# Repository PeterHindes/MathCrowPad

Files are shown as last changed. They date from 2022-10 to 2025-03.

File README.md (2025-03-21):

# MathCrowPad

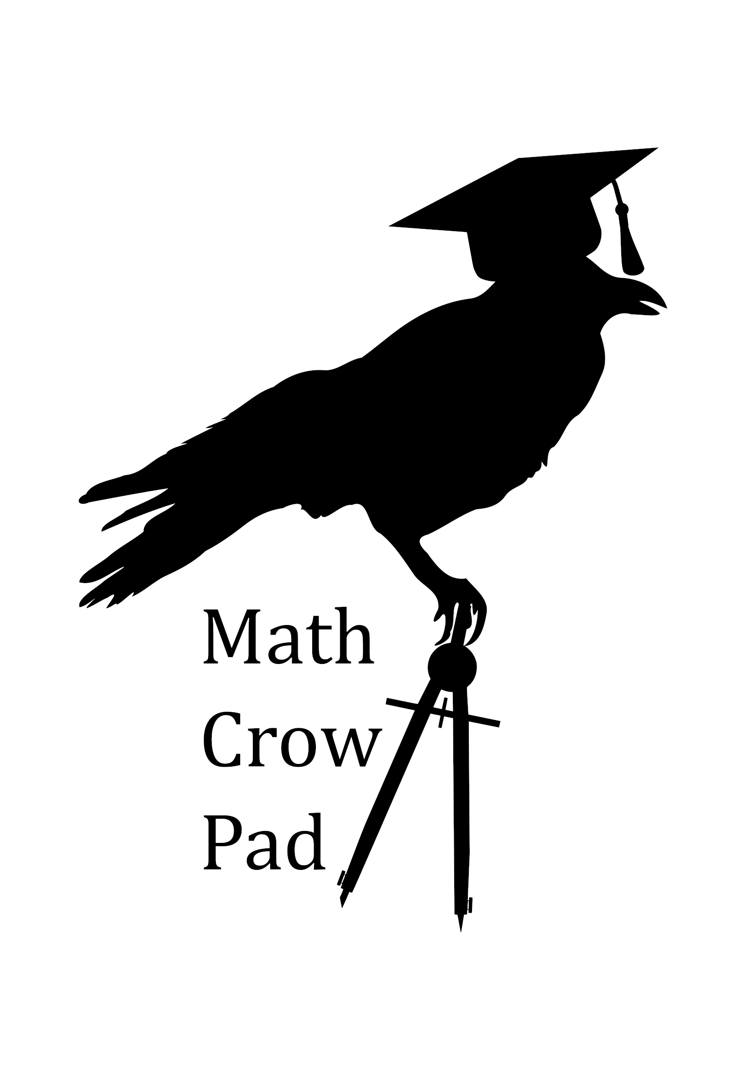
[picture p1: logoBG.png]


## The MathCrowPad is a numberpad for chemistry, math, and spreadsheets.

Its main three features are:
 * Two knobs to scroll through spreadsheets
 * An oled screen to show guides for the knobs
 * An extra row for parenthisis(), exponent^, factorial!, latex syntax$$ etc.

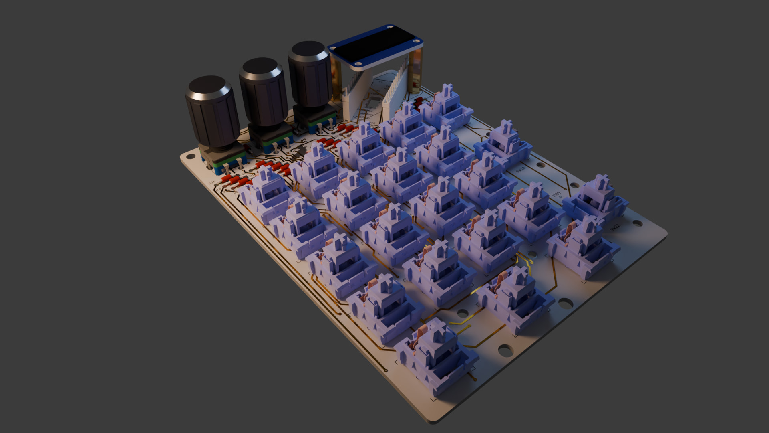
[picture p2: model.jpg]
model


Feel free to make up to 10 for personal use.

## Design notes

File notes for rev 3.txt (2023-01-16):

north facing leds are better for backlight shinethroughs
encoders with a single pad works gread

might need a diffrent footprint for bluetooth controllers
https://www.adafruit.com/product/5426

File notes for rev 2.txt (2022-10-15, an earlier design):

Issues with rev1:
X-The led library I made has the wrong pins -- Fixed rev2
X-The two top rotary encoders are not electricaly connected to ground, the ground plane is dissconnected -- removed ground plane, used new router, fixed
The rotary encoder non electrical holes are not plated for soldering -- fixed
Probably want to use a plate mount for v2 -- Holes added, check cad before order
screw hole on the bottom right, the screw head causes friction with the stabilizer bar -- fixed
stabilizer stickers cover the vanity logos -- logos removed
The miso pin may be a better driver for the rgb backlight look into qmk drivers -- used, testing needed when sample recived

Other Notes:
reset button on the kb2040 is hard to press when bottom mounted, top mount is possible with rev1 but not tested -- top mounted design complete
possibly add side mounted reset button to board like levinson -- not needed see above
unfixable without plate, switches lift up from unsoldered side
Matrix is not aligned with the key positions in the keymap. Perhaps the enter key should be moved up in th ematrix and the add key
The South paw logo is too small
Logos on back will be covered -- removed

Hardware Parts Selection:
The rotary encoders appear to trigger a rotation when they are clicked -- This may be a design error, investigating
Will need to order more kb2040s -- done

Current Design Notes TODO
X-no clearance for stema connector on top mounted design, route cable between keys with underside cutout -- replaced with rotated mount design
X-Consider pin socketed mounting -- done
X-consider hot swap keys -- incorporated in design
design needs to use switch plate which will require diffrent stabilizers -- ordered, check plate pattern fits in progress
Use jumpers to choose fast led or nkr for encoders

The CAD model for the oled does not line up with the screw holes

consider product name "Math Crow Pad" logo of a crow with a graduation cap

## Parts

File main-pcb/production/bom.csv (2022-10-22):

Designator | Footprint | Quantity | Value | LCSC Part #
D1, D10, D11, D12, D13, D14, D15, D16, D17, D18, D19, D2, D20, D21, D22, D23, D24, D25, D3, D4, D5, D6, D7, D8, D9 | Diode-dual | 25 | DIODE
FID1 | Fiducial_0.5mm_Mask1mm | 1 | Fiducial
JPSH1 | SolderJumper-3_P2.0mm_Open_TrianglePad1.0x1.5mm | 1 | Jumper_3_Open
JPSP2, JPSP3 | SolderJumper-2_P1.3mm_Open_TrianglePad1.0x1.5mm | 2 | Jumper_2_Open
RSW1, RSW2, RSW3 | RotaryEncoder_EC11 | 3 | RotaryEncoder_Switch
SW1, SW10, SW11, SW12, SW13, SW14, SW15, SW16, SW17, SW19, SW2, SW21, SW3, SW4, SW5, SW6, SW7, SW8, SW9 | SW_Cherry_MX_1.00u_PCB_WITH_SK6812MINI-E | 19 | SW_Push
SW18, SW20, SW22 | SW_Cherry_MX_2.00u_PCB_WITH_SK6812MINI-E | 3 | SW_Push
U1 | KB2040 through hole only (top mount with hotpins 3d model view) | 1 | KB2040

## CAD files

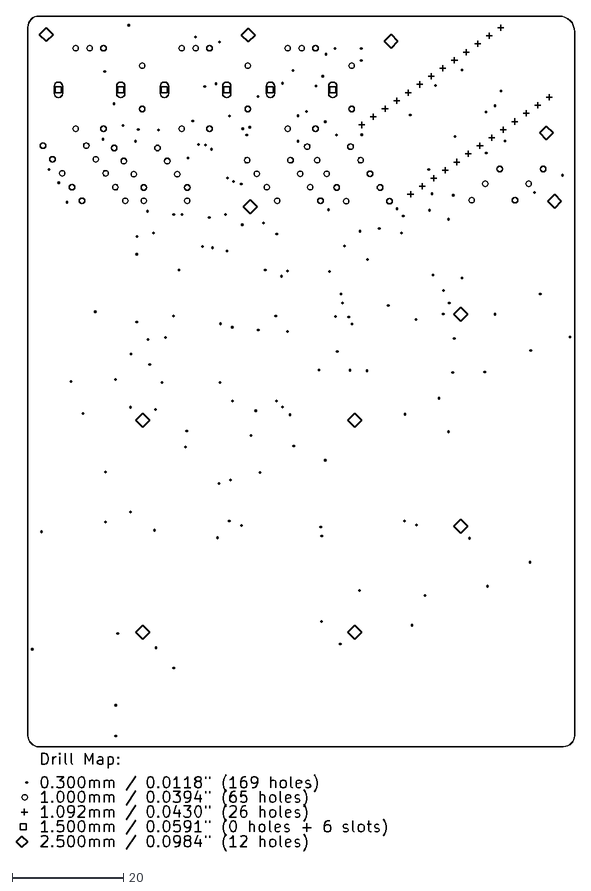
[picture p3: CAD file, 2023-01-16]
Mech Cad Files/plot/SouthPaw-PTH-drl_map.dxf
100.3 x 150.1

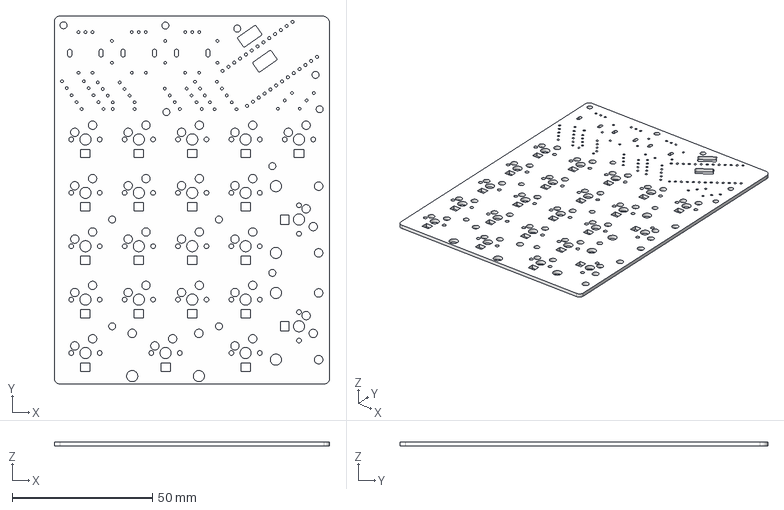
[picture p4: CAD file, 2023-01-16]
Mech Cad Files/SouthPaw PCB only.step
98.3 x 131.3 x 1.60 mm

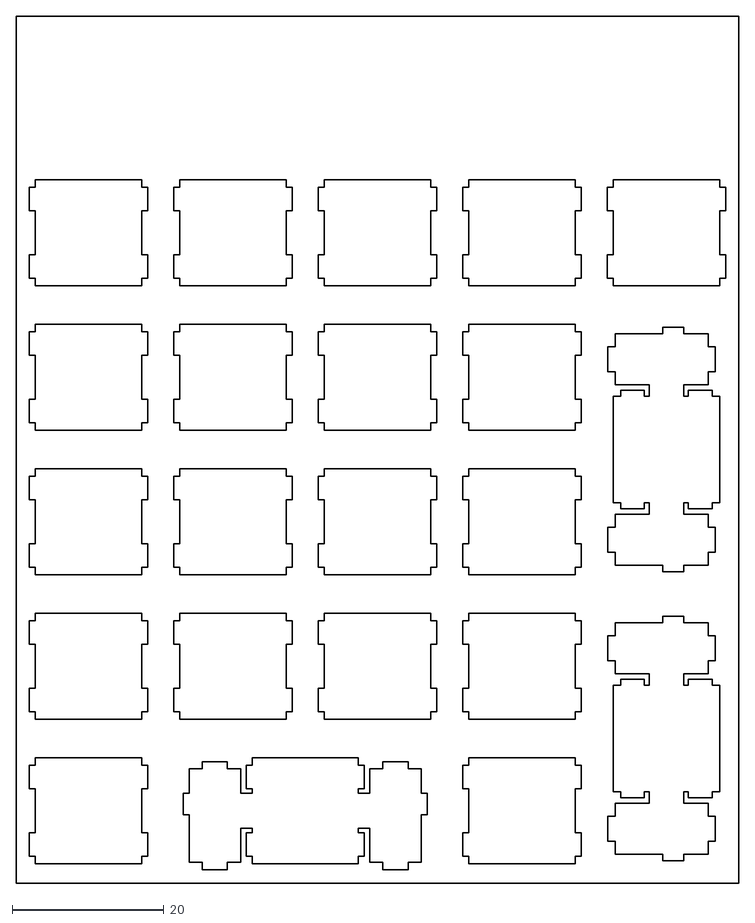
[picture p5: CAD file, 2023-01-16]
Mech Cad Files/156afa6cee5b1919b133f090e9bd5b217b3f6e2b_switch.dxf
95.3 x 114.3

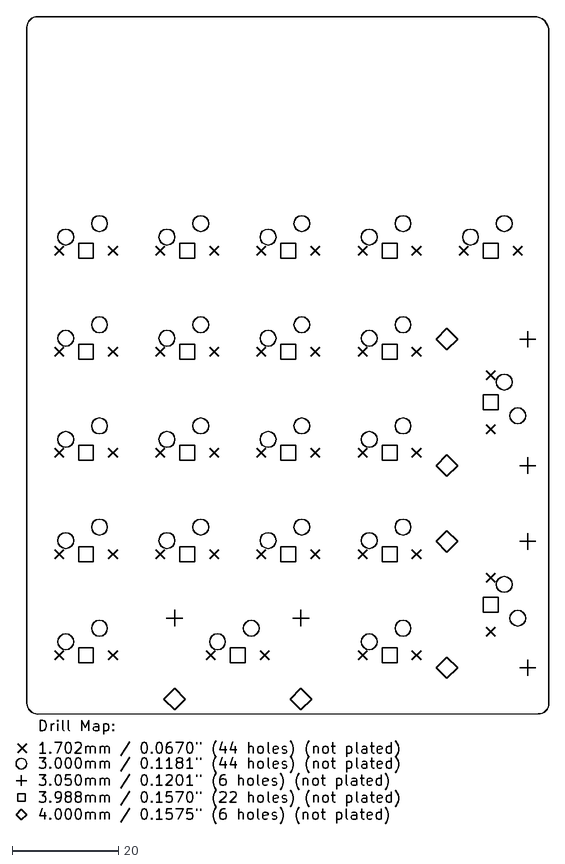
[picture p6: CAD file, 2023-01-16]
Mech Cad Files/plot/SouthPaw-NPTH-drl_map.dxf
100.3 x 152.0

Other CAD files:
Mech Cad Files/SouthPaw PCB.stl
Mech Cad Files/plot/SouthPaw-F_Mask.dxf

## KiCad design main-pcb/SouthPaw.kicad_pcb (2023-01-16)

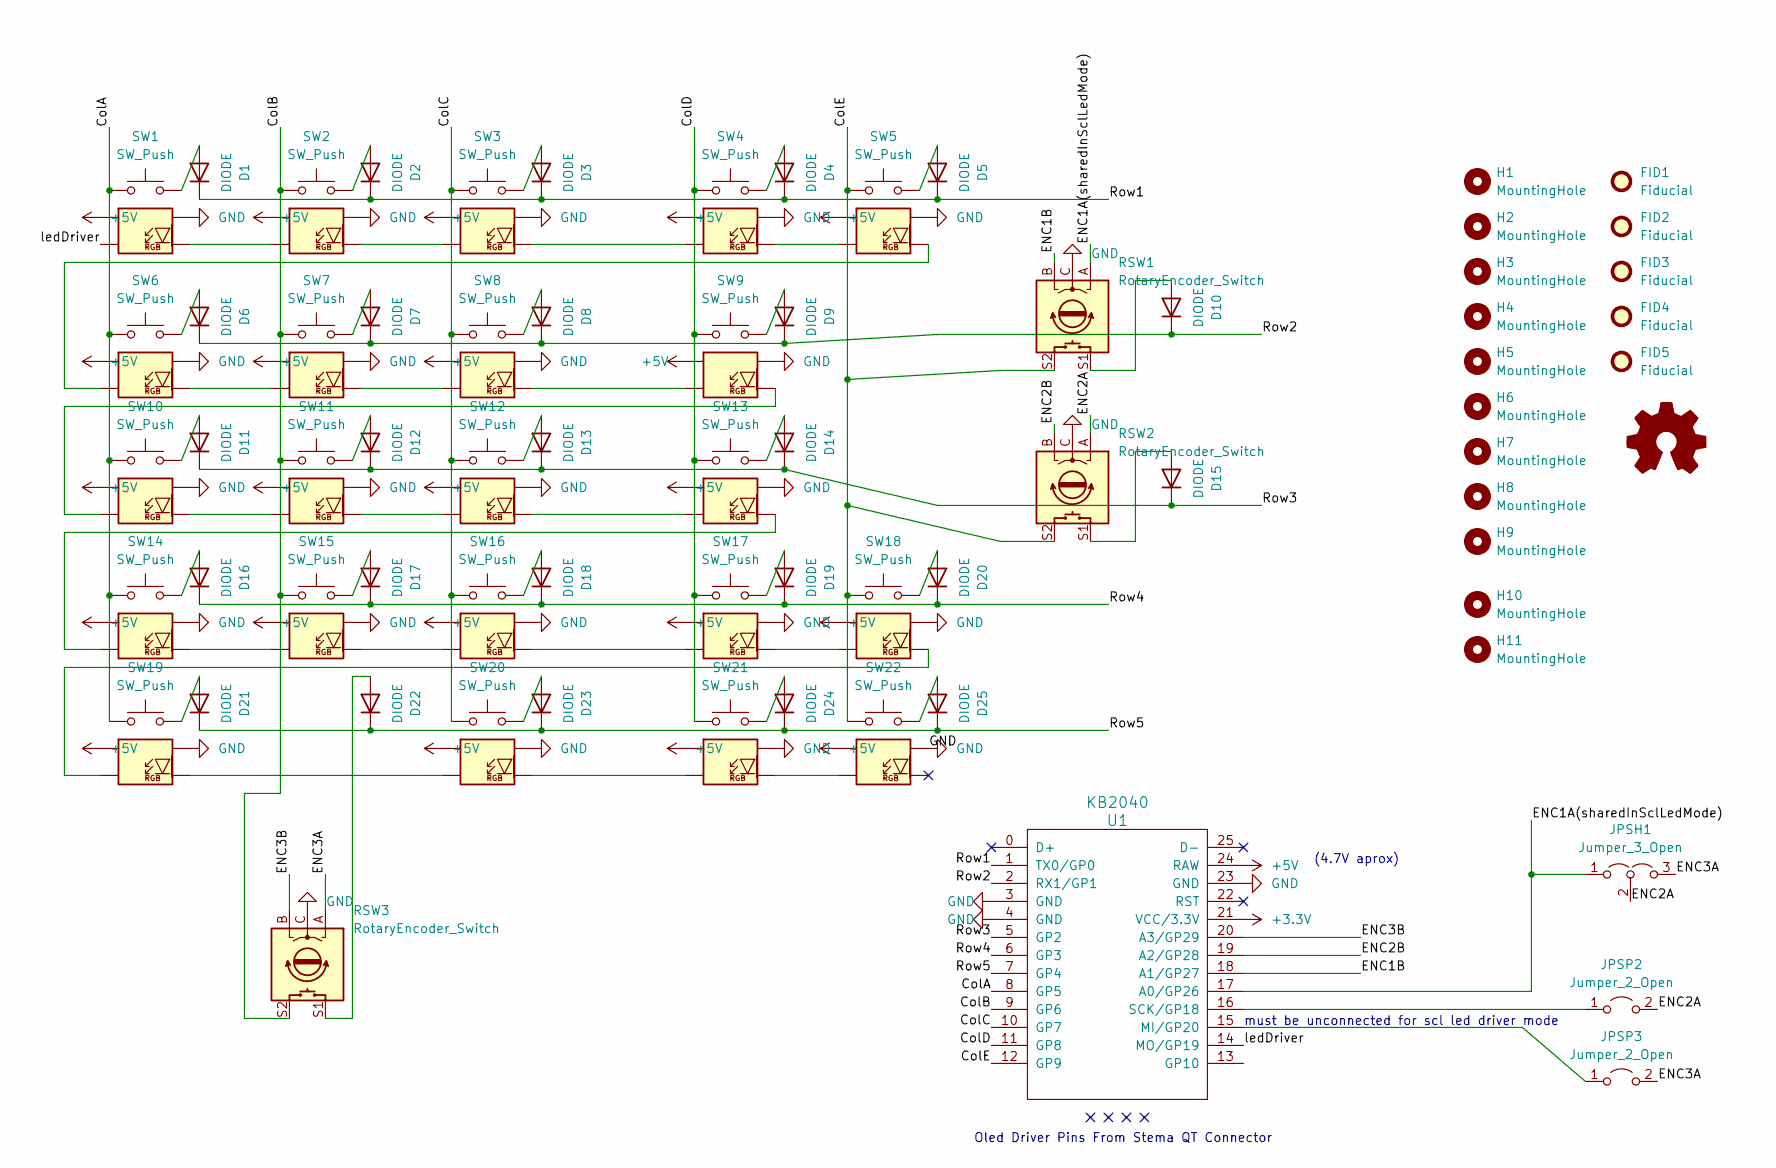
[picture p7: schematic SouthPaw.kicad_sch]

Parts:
D1, D2, D3, D4, D5, D6, D7, D8, D9, D10, D11, D12, D13, D14, D15, D16, D17, D18, D19, D20, D21, D22, D23, D24, D25: DIODE; Diode-dual
FID1, FID2, FID3, FID4, FID5: Fiducial; Fiducial_0.5mm_Mask1mm
H1: MountingHole; 0.91in 128x32 I2C STEMMA QT standoff only with cutout
H2, H3, H4, H5, H6, H7, H8, H9, H10, H11: MountingHole; m2.5 hole
JPSH1: Jumper_3_Open; SolderJumper-3_P2.0mm_Open_TrianglePad1.0x1.5mm
JPSP2, JPSP3: Jumper_2_Open; SolderJumper-2_P1.3mm_Open_TrianglePad1.0x1.5mm
RSW1, RSW2, RSW3: RotaryEncoder_Switch; RotaryEncoder_EC11
SW1, SW2, SW3, SW4, SW5, SW6, SW7, SW8, SW9, SW10, SW11, SW12, SW13, SW14, SW15, SW16, SW17, SW19, SW21: SW_Push; SW_Cherry_MX_1.00u_PCB_WITH_SK6812MINI-E
SW18, SW20, SW22: SW_Push; SW_Cherry_MX_2.00u_PCB_WITH_SK6812MINI-E
U1: KB2040; KB2040 through hole only (top mount with hotpins 3d model v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

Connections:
+3.3V: U1.21 (VCC/3.3V)
+5V: SW1.21 (ledVDD), SW2.21 (ledVDD), SW3.21 (ledVDD), SW4.21 (ledVDD), SW5.21 (ledVDD), SW6.21 (ledVDD), SW7.21 (ledVDD), SW8.21 (ledVDD), SW9.21 (ledVDD), SW10.21 (ledVDD), SW11.21 (ledVDD), SW12.21 (ledVDD), SW13.21 (ledVDD), SW14.21 (ledVDD), SW15.21 (ledVDD), SW16.21 (ledVDD), SW17.21 (ledVDD), SW18.21 (ledVDD), SW19.21 (ledVDD), SW20.21 (ledVDD), SW21.21 (ledVDD), SW22.21 (ledVDD), U1.24 (RAW)
/ColA: SW1.11 (sw1), SW6.11 (sw1), SW10.11 (sw1), SW14.11 (sw1), SW19.11 (sw1), U1.8 (GP5)
/ColB: RSW3.S2, SW2.11 (sw1), SW7.11 (sw1), SW11.11 (sw1), SW15.11 (sw1), U1.9 (GP6)
/ColC: SW3.11 (sw1), SW8.11 (sw1), SW12.11 (sw1), SW16.11 (sw1), SW20.11 (sw1), U1.10 (GP7)
/ColD: SW4.11 (sw1), SW9.11 (sw1), SW13.11 (sw1), SW17.11 (sw1), SW21.11 (sw1), U1.11 (GP8)
/ColE: RSW1.S2, RSW2.S2, SW5.11 (sw1), SW18.11 (sw1), SW22.11 (sw1), U1.12 (GP9)
/ENC1A(sharedInSclLedMode): JPSH1.1 (A), RSW1.A, U1.17 (A0/GP26)
/ENC1B: RSW1.B, U1.18 (A1/GP27)
/ENC2A: JPSH1.2 (C), JPSP2.2 (B), RSW2.A
/ENC2B: RSW2.B, U1.19 (A2/GP28)
/ENC3A: JPSH1.3 (B), JPSP3.2 (B), RSW3.A
/ENC3B: RSW3.B, U1.20 (A3/GP29)
/Row1: D1.2 (K), D2.2 (K), D3.2 (K), D4.2 (K), D5.2 (K), U1.1 (TX0/GP0)
/Row2: D6.2 (K), D7.2 (K), D8.2 (K), D9.2 (K), D10.2 (K), U1.2 (RX1/GP1)
/Row3: D11.2 (K), D12.2 (K), D13.2 (K), D14.2 (K), D15.2 (K), U1.5 (GP2)
/Row4: D16.2 (K), D17.2 (K), D18.2 (K), D19.2 (K), D20.2 (K), U1.6 (GP3)
/Row5: D21.2 (K), D22.2 (K), D23.2 (K), D24.2 (K), D25.2 (K), U1.7 (GP4)
/ledDriver: SW1.24 (ledDIN), U1.14 (MO/GP19)
GND: RSW1.C, RSW2.C, RSW3.C, SW1.23 (ledGND), SW2.23 (ledGND), SW3.23 (ledGND), SW4.23 (ledGND), SW5.23 (ledGND), SW6.23 (ledGND), SW7.23 (ledGND), SW8.23 (ledGND), SW9.23 (ledGND), SW10.23 (ledGND), SW11.23 (ledGND), SW12.23 (ledGND), SW13.23 (ledGND), SW14.23 (ledGND), SW15.23 (ledGND), SW16.23 (ledGND), SW17.23 (ledGND), SW18.23 (ledGND), SW19.23 (ledGND), SW20.23 (ledGND), SW21.23 (ledGND), SW22.23 (ledGND), U1.3 (GND), U1.4 (GND), U1.23 (GND)
unnamed: D1.1 (A), SW1.12 (sw2)
unnamed: D2.1 (A), SW2.12 (sw2)
unnamed: D3.1 (A), SW3.12 (sw2)
unnamed: D4.1 (A), SW4.12 (sw2)
unnamed: D5.1 (A), SW5.12 (sw2)
unnamed: D6.1 (A), SW6.12 (sw2)
unnamed: D7.1 (A), SW7.12 (sw2)
unnamed: D8.1 (A), SW8.12 (sw2)
unnamed: D9.1 (A), SW9.12 (sw2)
unnamed: D10.1 (A), RSW1.S1
unnamed: D11.1 (A), SW10.12 (sw2)
unnamed: D12.1 (A), SW11.12 (sw2)
unnamed: D13.1 (A), SW12.12 (sw2)
unnamed: D14.1 (A), SW13.12 (sw2)
unnamed: D15.1 (A), RSW2.S1
unnamed: D16.1 (A), SW14.12 (sw2)
unnamed: D17.1 (A), SW15.12 (sw2)
unnamed: D18.1 (A), SW16.12 (sw2)
unnamed: D19.1 (A), SW17.12 (sw2)
unnamed: D20.1 (A), SW18.12 (sw2)
unnamed: D21.1 (A), SW19.12 (sw2)
unnamed: D22.1 (A), RSW3.S1
unnamed: D23.1 (A), SW20.12 (sw2)
unnamed: D24.1 (A), SW21.12 (sw2)
unnamed: D25.1 (A), SW22.12 (sw2)
unnamed: JPSP2.1 (A), U1.16 (SCK/GP18)
unnamed: JPSP3.1 (A), U1.15 (MI/GP20)
unnamed: SW1.22 (ledDOUT), SW2.24 (ledDIN)
unnamed: SW2.22 (ledDOUT), SW3.24 (ledDIN)
unnamed: SW3.22 (ledDOUT), SW4.24 (ledDIN)
unnamed: SW4.22 (ledDOUT), SW5.24 (ledDIN)
unnamed: SW5.22 (ledDOUT), SW6.24 (ledDIN)
unnamed: SW6.22 (ledDOUT), SW7.24 (ledDIN)
unnamed: SW7.22 (ledDOUT), SW8.24 (ledDIN)
unnamed: SW8.22 (ledDOUT), SW9.24 (ledDIN)
unnamed: SW10.22 (ledDOUT), SW11.24 (ledDIN)
unnamed: SW9.22 (ledDOUT), SW10.24 (ledDIN)
unnamed: SW11.22 (ledDOUT), SW12.24 (ledDIN)
unnamed: SW12.22 (ledDOUT), SW13.24 (ledDIN)
unnamed: SW13.22 (ledDOUT), SW14.24 (ledDIN)
unnamed: SW14.22 (ledDOUT), SW15.24 (ledDIN)
unnamed: SW15.22 (ledDOUT), SW16.24 (ledDIN)
unnamed: SW16.22 (ledDOUT), SW17.24 (ledDIN)
unnamed: SW17.22 (ledDOUT), SW18.24 (ledDIN)
unnamed: SW18.22 (ledDOUT), SW19.24 (ledDIN)
unnamed: SW19.22 (ledDOUT), SW20.24 (ledDIN)
unnamed: SW20.22 (ledDOUT), SW21.24 (ledDIN)
unnamed: SW21.22 (ledDOUT), SW22.24 (ledDIN)

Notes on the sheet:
Oled Driver Pins From Stema QT Connector
must be unconnected for scl led driver mode
(4.7V aprox)

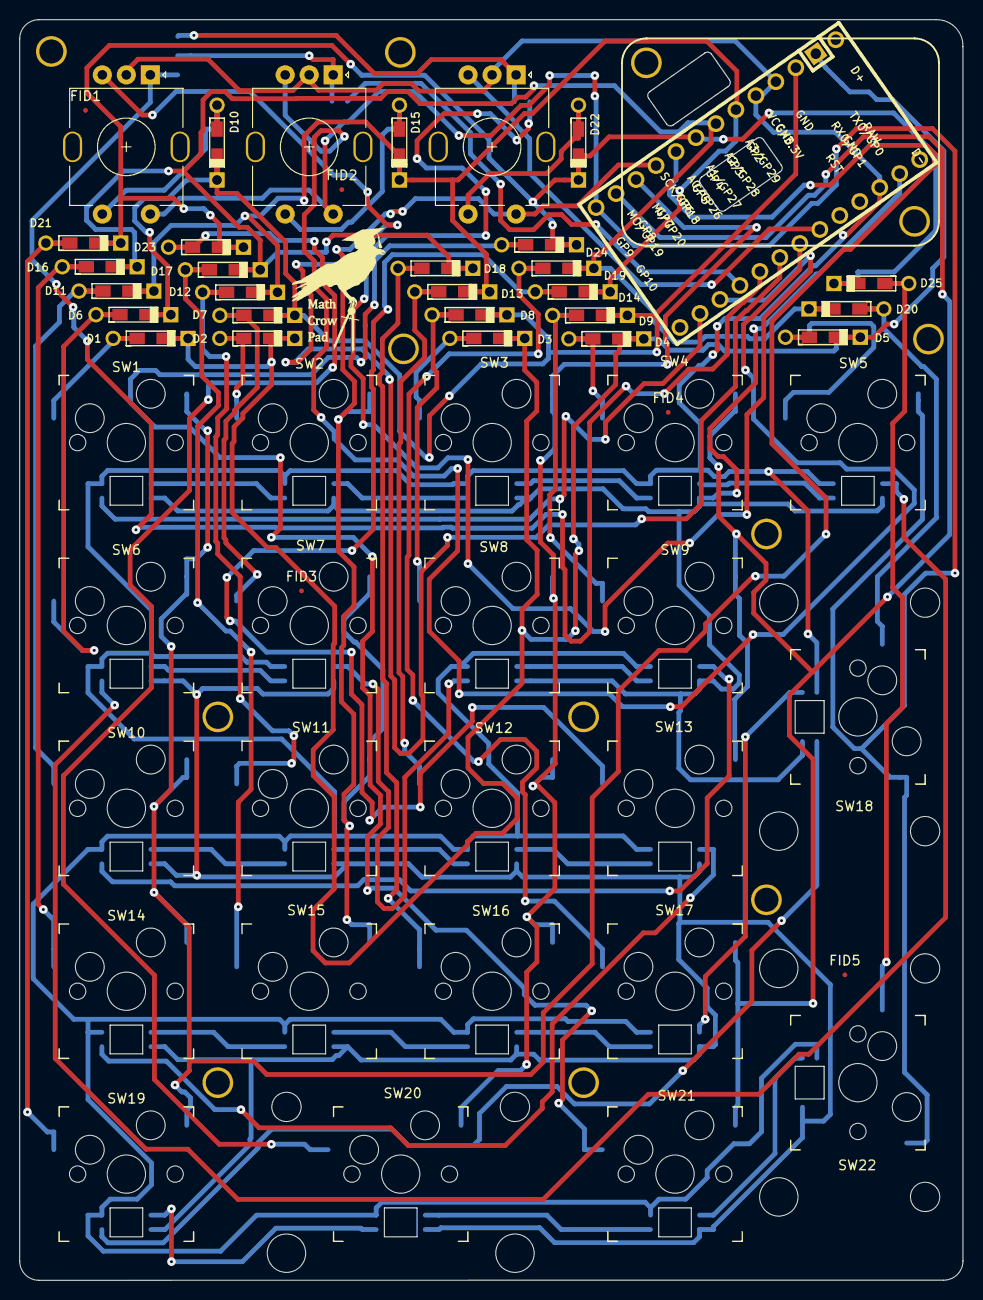
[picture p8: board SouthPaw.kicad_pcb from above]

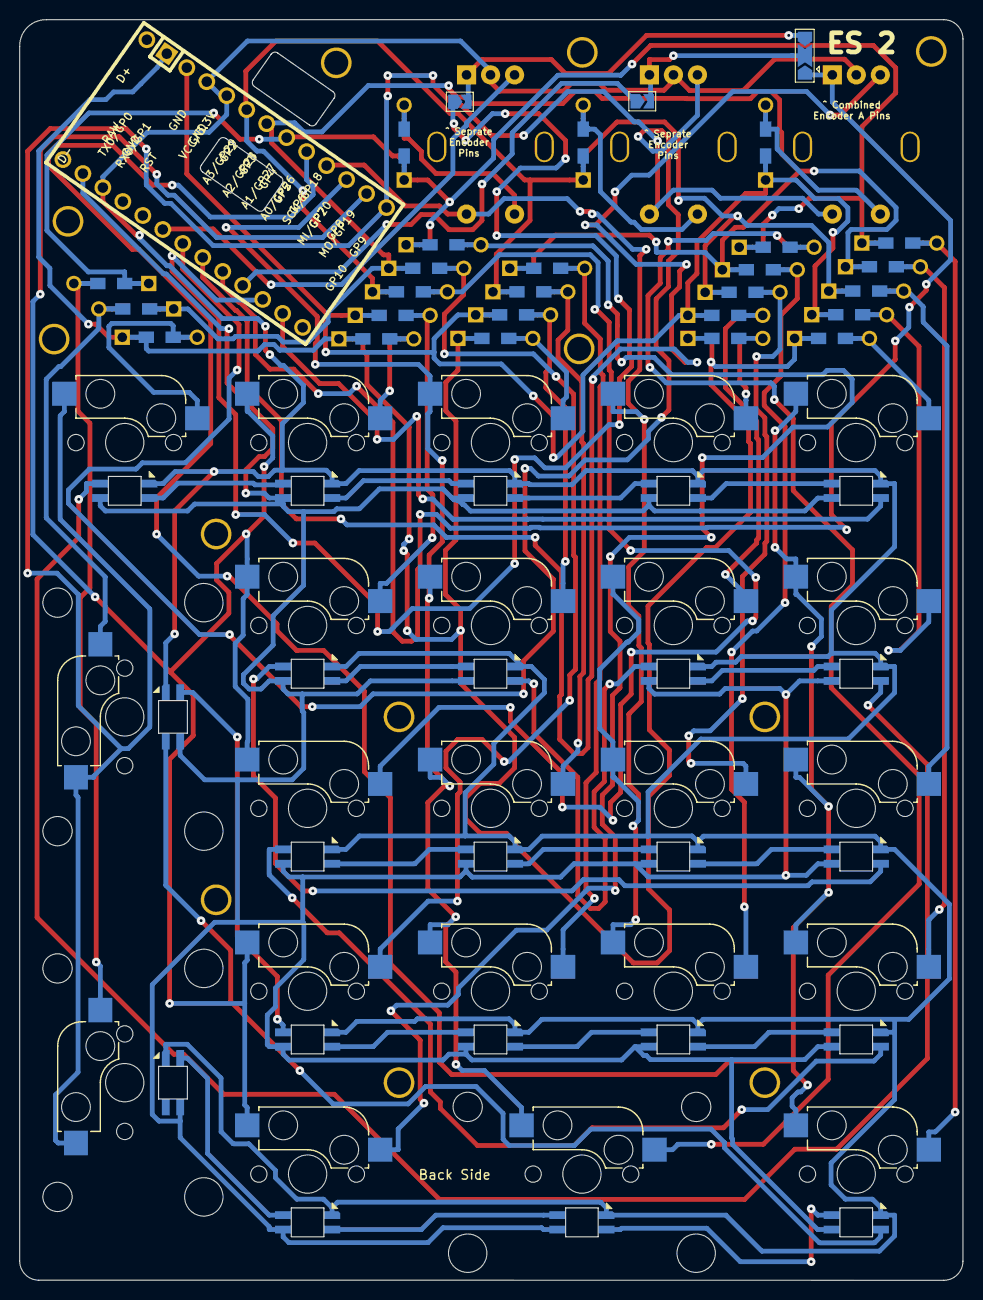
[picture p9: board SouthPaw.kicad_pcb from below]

Board: 2 copper layers, 98.3 x 131.3 mm, 70 parts (3 on the bottom side), 67 nets.

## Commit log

2022-09-18 Cleanup My Mess
    [SouthPaw.kicad_pcb, SouthPaw.kicad_sch, bom.csv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]
2022-09-18 Part one of footprint cleanup
2022-09-18 Making progress
    [SouthPaw.dsn, SouthPaw.kicad_pcb]
2022-09-19 Start on plate cad
2022-09-19 Update PeteCB-Kicad-Library
2022-09-19 Complete Switch plate
    Fitment testes still needed
2022-09-21 more progress with switch plate
2022-10-06 fixed pinnouts
    rotary encoders now all share a common a pin
    [SouthPaw.dsn, SouthPaw.kicad_pcb, SouthPaw.kicad_sch]
2022-10-07 Some work on traces (drc errors present)
    [SouthPaw.dsn, SouthPaw.kicad_pcb, SouthPaw.kicad_sch]
2022-10-07 fixed schematic errors
    [SouthPaw.dsn, SouthPaw.kicad_pcb, SouthPaw.kicad_sch]
2022-10-15 routing underway
    [SouthPaw PCB only.step, SouthPaw PCB.stl, SouthPaw.dsn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]
2022-10-22 I think Im finished with es2
    [SouthPaw.dsn, SouthPaw.kicad_pcb, SouthPaw.kicad_sch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]
2022-10-23 added clarity to schematic that does not change electrical
2022-10-27 New Logo New Name
    [SouthPaw.dsn]
2022-10-27 Logo inserted without vias below
    [SouthPaw.kicad_pcb, positions.csv]
2023-01-03 Some mech cad progress
    [156afa6cee5b1919b133f090e9bd5b217b3f6e2b_switch.dxf, SouthPaw PCB only.step, SouthPaw-F_Mask.dxf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]
